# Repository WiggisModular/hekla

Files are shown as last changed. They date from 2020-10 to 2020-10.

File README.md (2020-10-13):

# hekla

FeatherWing Eurorack module, optimised for the Feather M4 express. I designed it to act as a slow LFO using DAC0 and DAC1 for two channels. 

## Resources (AKA giants on which shoulder I built)

### Featherwing

https://forum.kicad.info/t/designing-featherwings-in-kicad/6115/2

### Outputs and stuff: 

https://blog.thea.codes/designing-big-honking-button/

BTW: Follow her on twitter, read her blog, buy her modules. Wholesome content from a kickass person.

### Frontpanel copper layer 

Original data https://commons.wikimedia.org/wiki/File:Hekla1980.jpg#/media/File:Hekla1980.jpg

## Production files

Gerber, a schematic and a placement drawing, as well as a BOM and a pick and place file to get the SMD parts assembled over at JLCPCB will be available as releases as soon as I tested the first batch.

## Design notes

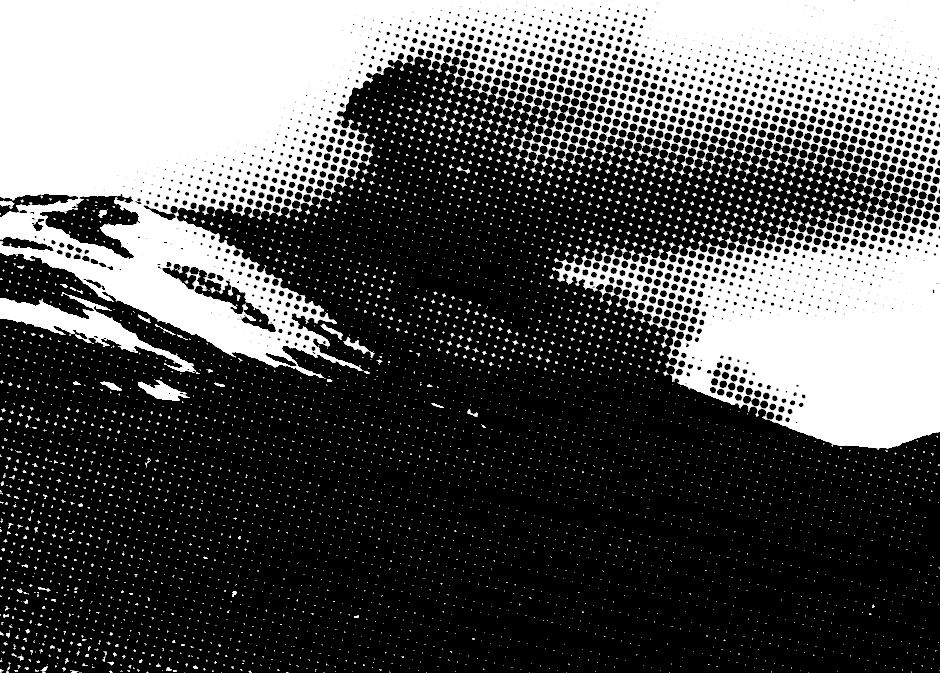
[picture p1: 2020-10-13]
panel/bg.jpg

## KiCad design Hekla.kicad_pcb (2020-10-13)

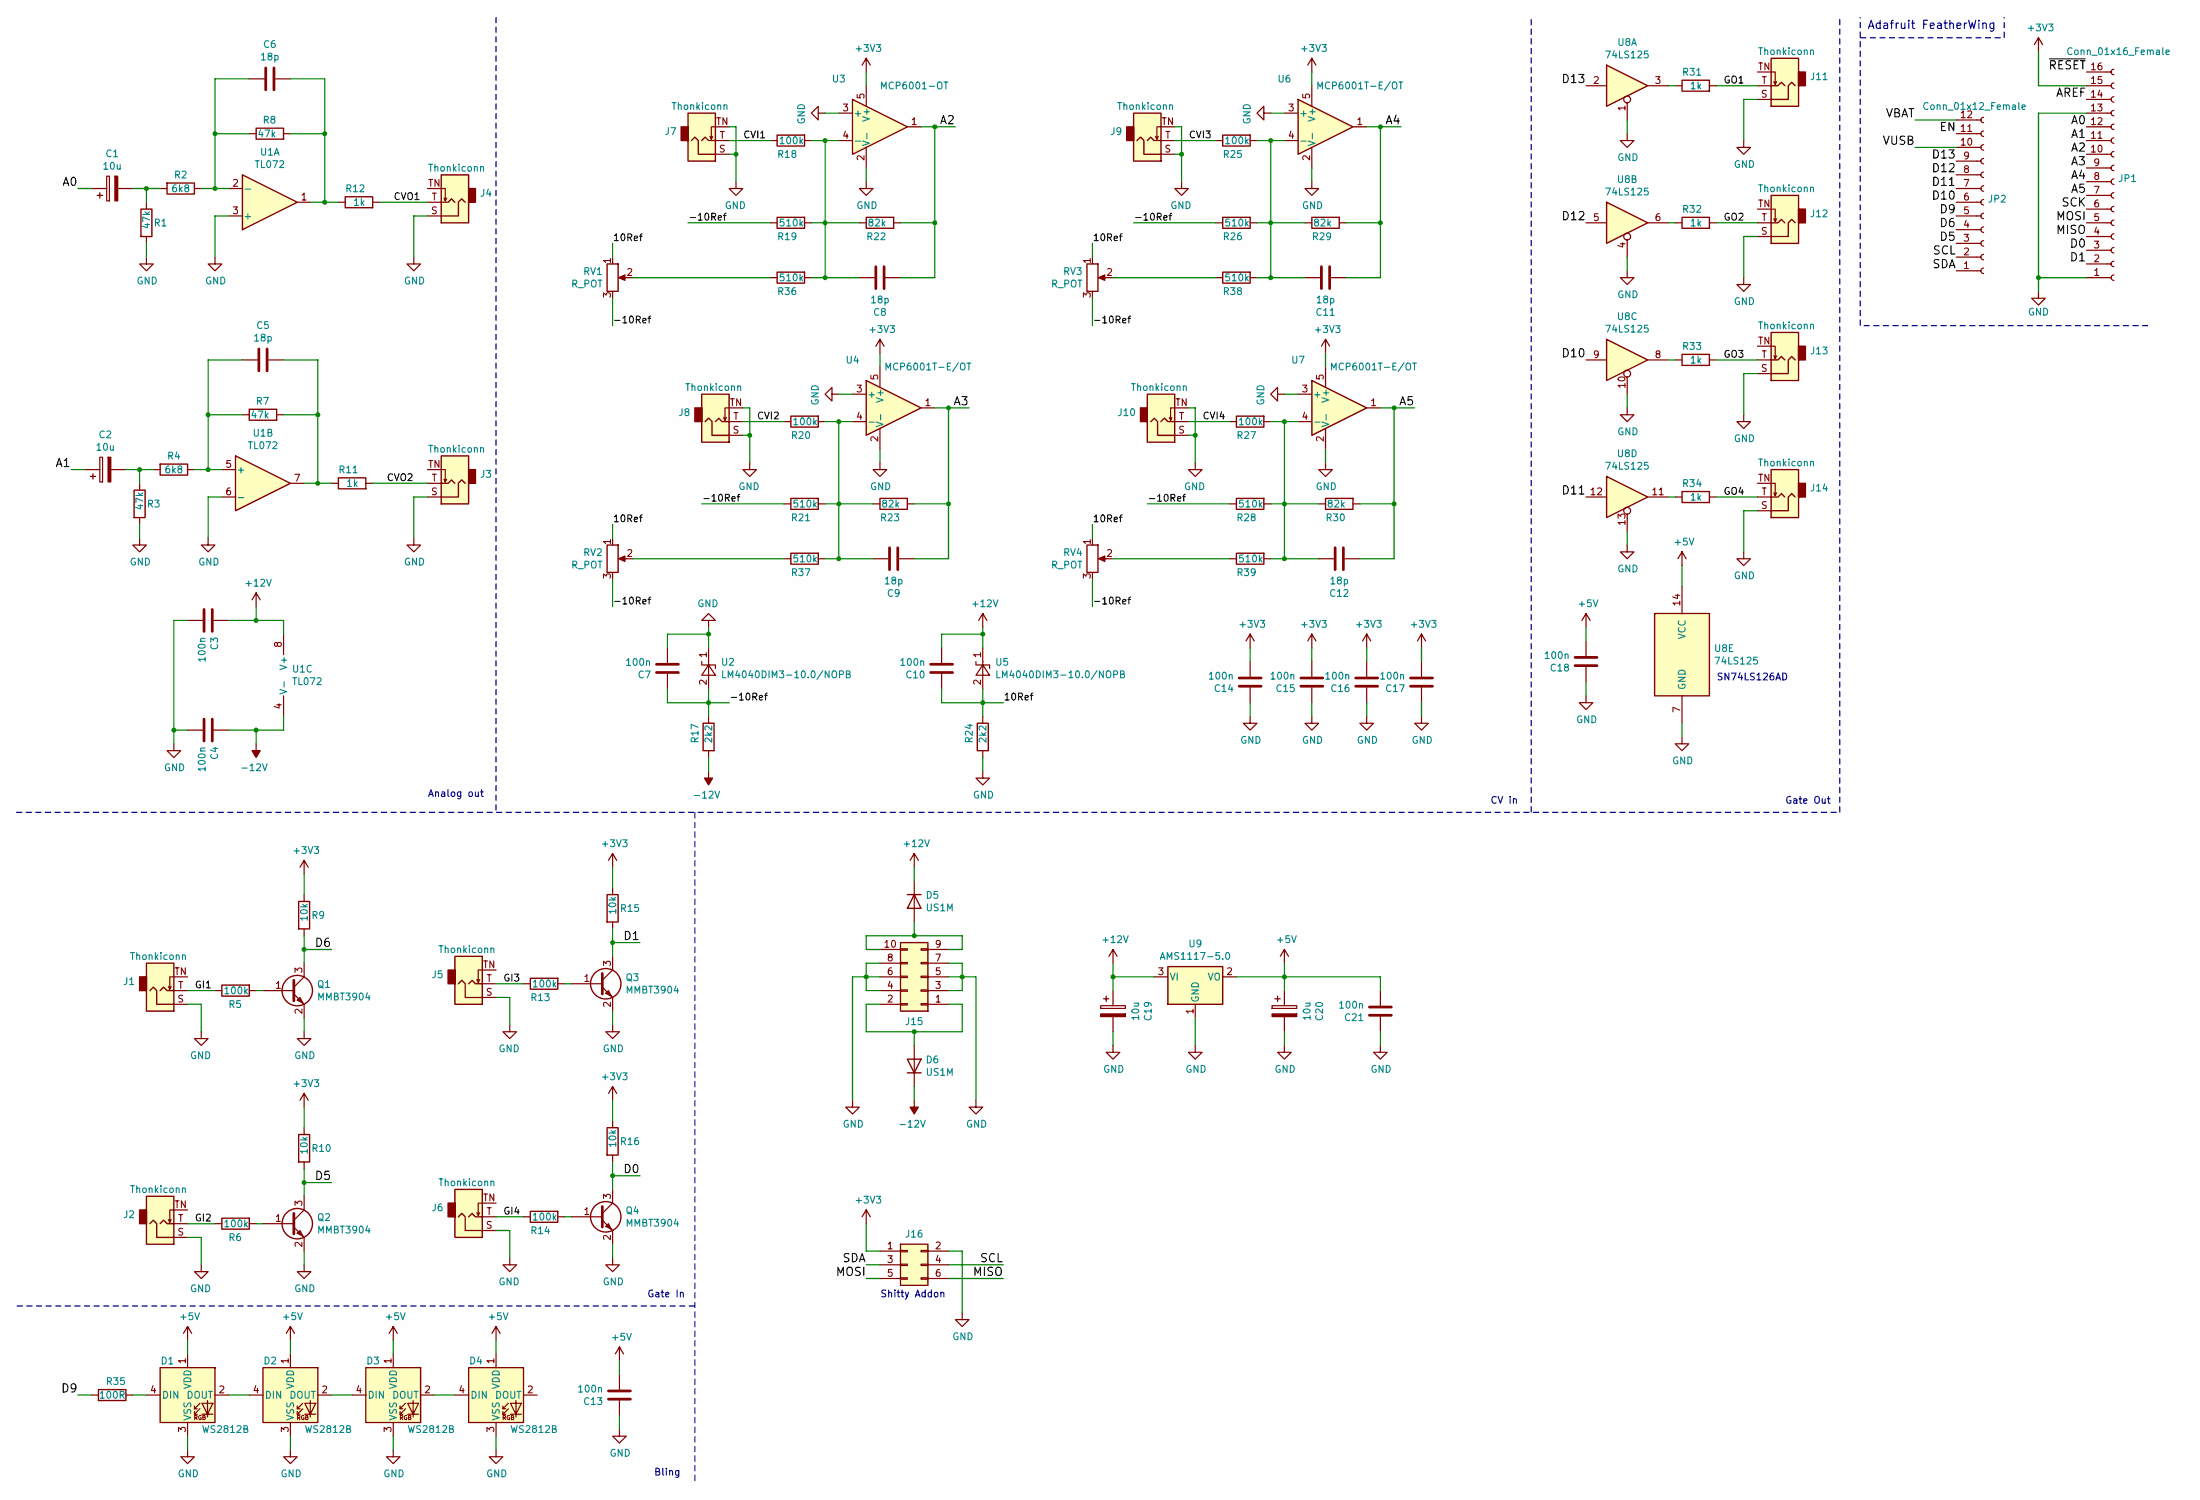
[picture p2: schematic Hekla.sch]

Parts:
C1, C2, C19, C20: 10u; CP_Elec_3x5.3; LCSC C249452
C3, C4, C7, C10, C13, C14, C15, C16, C17, C18, C21: 100n; C_0603_1608Metric_Pad1.05x0.95mm_HandSolder; LCSC C14663
C5, C6, C8, C9, C11, C12: 18p; C_0603_1608Metric_Pad1.05x0.95mm_HandSolder; LCSC C1647
D1, D2, D3, D4: WS2812B; LED_WS2812B_PLCC4_5.0x5.0mm_P3.2mm
D5, D6: US1M; D_SMA; LCSC C412437
J1, J2, J3, J4, J5, J6, J7, J8, J9, J10, J11, J12, J13, J14: Thonkiconn; Jack_3.5mm_QingPu_WQP-PJ398SM_Vertical_CircularHoles
J15: Conn_02x05_Odd_Even; PinSocket_2x05_P2.54mm_Vertical
J16: Conn_02x03_Odd_Even; PinSocket_2x03_P2.54mm_Vertical
JP1: Conn_01x16_Female; PinSocket_1x16_P2.54mm_Vertical
JP2: Conn_01x12_Female; PinSocket_1x12_P2.54mm_Vertical
Q1, Q2, Q3, Q4: MMBT3904; SOT-23; LCSC C20526
R1, R3, R7, R8: 47k; R_0603_1608Metric_Pad1.05x0.95mm_HandSolder; LCSC C25819
R2, R4: 6k8; R_0603_1608Metric_Pad1.05x0.95mm_HandSolder; LCSC C23212
R5, R6, R13, R14, R18, R20, R25, R27: 100k; R_0603_1608Metric_Pad1.05x0.95mm_HandSolder; LCSC C25803
R9, R10, R15, R16: 10k; R_0603_1608Metric_Pad1.05x0.95mm_HandSolder; LCSC C25804
R11, R12, R31, R32, R33, R34: 1k; R_0603_1608Metric_Pad1.05x0.95mm_HandSolder; LCSC C21190
R17, R24: 2k2; R_0603_1608Metric_Pad1.05x0.95mm_HandSolder; LCSC C4190
R19, R21, R26, R28, R36, R37, R38, R39: 510k; R_0603_1608Metric_Pad1.05x0.95mm_HandSolder; LCSC C23192
R22, R23, R29, R30: 82k; R_0603_1608Metric_Pad1.05x0.95mm_HandSolder; LCSC C23254
R35: 100R; R_0603_1608Metric_Pad1.05x0.95mm_HandSolder; LCSC C22775
RV1, RV2, RV3, RV4: R_POT; Potentiometer_Alps_RK09L_Single_Vertical
U1: TL072; SOIC-8_3.9x4.9mm_P1.27mm; LCSC C6961
U2, U5: LM4040DIM3-10.0/NOPB; SOT-23; LCSC C129969
U3: MCP6001-OT; SOT-23-5; LCSC C29429
U4, U6, U7: MCP6001T-E/OT; SOT-23-5; LCSC C29429
U8: 74LS125; SOIC-14_3.9x8.7mm_P1.27mm; LCSC C7734
U9: AMS1117-5.0; SOT-223-3_TabPin2; LCSC C6187

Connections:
+3V3: C14.1, C15.1, C16.1, C17.1, J16.1, JP1.15, R9.1, R10.1, R15.1, R16.1, U3.5 (V+), U4.5 (V+), U6.5 (V+), U7.5 (V+)
+5V: C13.1, C18.1, C20.1, C21.1, D1.1 (VDD), D2.1 (VDD), D3.1 (VDD), D4.1 (VDD), U8.14 (VCC), U9.2 (VO)
+12V: C3.2, C10.1, C19.1, D5.1 (K), U1.8 (V+), U5.1 (K), U9.3 (VI)
-12V: C4.2, D6.1 (K), R17.2, U1.4 (V-)
/10Ref: C10.2, R24.1, RV1.1, RV2.1, RV3.1, RV4.1, U5.2 (A)
/-10Ref: C7.2, R17.1, R19.1, R21.1, R26.1, R28.1, RV1.3, RV2.3, RV3.3, RV4.3, U2.2 (A)
/A0: C1.1, JP1.12
/A1: C2.1, JP1.11
/A2: C8.1, JP1.10, R22.2, U3.1
/A3: C9.1, JP1.9, R23.2, U4.1
/A4: C11.1, JP1.8, R29.2, U6.1
/A5: C12.1, JP1.7, R30.2, U7.1
/AREF: JP1.14
/CVI1: J7.T, R18.1
/CVI2: J8.T, R20.1
/CVI3: J9.T, R25.1
/CVI4: J10.T, R27.1
/CVO1: J4.T, R12.2
/CVO2: J3.T, R11.2
/D0: JP1.3, Q4.3 (C), R16.2
/D1: JP1.2, Q3.3 (C), R15.2
/D5: JP2.3, Q2.3 (C), R10.2
/D6: JP2.4, Q1.3 (C), R9.2
/D9: JP2.5, R35.2
/D10: JP2.6, U8.9
/D11: JP2.7, U8.12
/D12: JP2.8, U8.5
/D13: JP2.9, U8.2
/EN: JP2.11
/GI1: J1.T, R5.1
/GI2: J2.T, R6.1
/GI3: J5.T, R13.1
/GI4: J6.T, R14.1
/GO1: J11.T, R31.2
/GO2: J12.T, R32.2
/GO3: J13.T, R33.2
/GO4: J14.T, R34.2
/MISO: J16.6, JP1.4
/MOSI: J16.5, JP1.5
/SCK: JP1.6
/SCL: J16.4, JP2.2
/SDA: J16.3, JP2.1
/VBAT: JP2.12
/VUSB: JP2.10
/~RESET: JP1.16
GND: C3.1, C4.1, C7.1, C13.2, C14.2, C15.2, C16.2, C17.2, C18.2, C19.2, C20.2, C21.2, D1.3 (VSS), D2.3 (VSS), D3.3 (VSS), D4.3 (VSS), J1.S, J2.S, J3.S, J4.S, J5.S, J6.S, J7.S, J7.TN, J8.S, J8.TN, J9.S, J9.TN, J10.S, J10.TN, J11.S, J12.S, J13.S, J14.S, J15.3, J15.4, J15.5, J15.6, J15.7, J15.8, J16.2, JP1.1, JP1.13, Q1.2 (E), Q2.2 (E), Q3.2 (E), Q4.2 (E), R1.2, R3.2, R24.2, U1.3 (+), U1.6 (-), U2.1 (K), U3.2 (V-), U3.3 (+), U4.2 (V-), U4.3 (+), U6.2 (V-), U6.3 (+), U7.2 (V-), U7.3 (+), U8.1, U8.4, U8.7 (GND), U8.10, U8.13, U9.1 (GND)
unnamed: C1.2, R1.1, R2.2
unnamed: C2.2, R3.1, R4.2
unnamed: C5.1, R7.2, R11.1, U1.7
unnamed: C5.2, R4.1, R7.1, U1.5 (+)
unnamed: C6.1, R8.2, R12.1, U1.1
unnamed: C6.2, R2.1, R8.1, U1.2 (-)
unnamed: C8.2, R18.2, R19.2, R22.1, R36.2, U3.4 (-)
unnamed: C9.2, R20.2, R21.2, R23.1, R37.2, U4.4 (-)
unnamed: C11.2, R25.2, R26.2, R29.1, R38.2, U6.4 (-)
unnamed: C12.2, R27.2, R28.2, R30.1, R39.2, U7.4 (-)
unnamed: D1.2 (DOUT), D2.4 (DIN)
unnamed: D1.4 (DIN), R35.1
unnamed: D2.2 (DOUT), D3.4 (DIN)
unnamed: D3.2 (DOUT), D4.4 (DIN)
unnamed: D5.2 (A), J15.9, J15.10
unnamed: D6.2 (A), J15.1, J15.2
unnamed: Q1.1 (B), R5.2
unnamed: Q2.1 (B), R6.2
unnamed: Q3.1 (B), R13.2
unnamed: Q4.1 (B), R14.2
unnamed: R31.1, U8.3
unnamed: R32.1, U8.6
unnamed: R33.1, U8.8
unnamed: R34.1, U8.11
unnamed: R36.1, RV1.2
unnamed: R37.1, RV2.2
unnamed: R38.1, RV3.2
unnamed: R39.1, RV4.2

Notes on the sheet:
Adafruit FeatherWing
Analog out
CV in
Gate Out
Gate In
SN74LS126AD
Bling
Shitty Addon

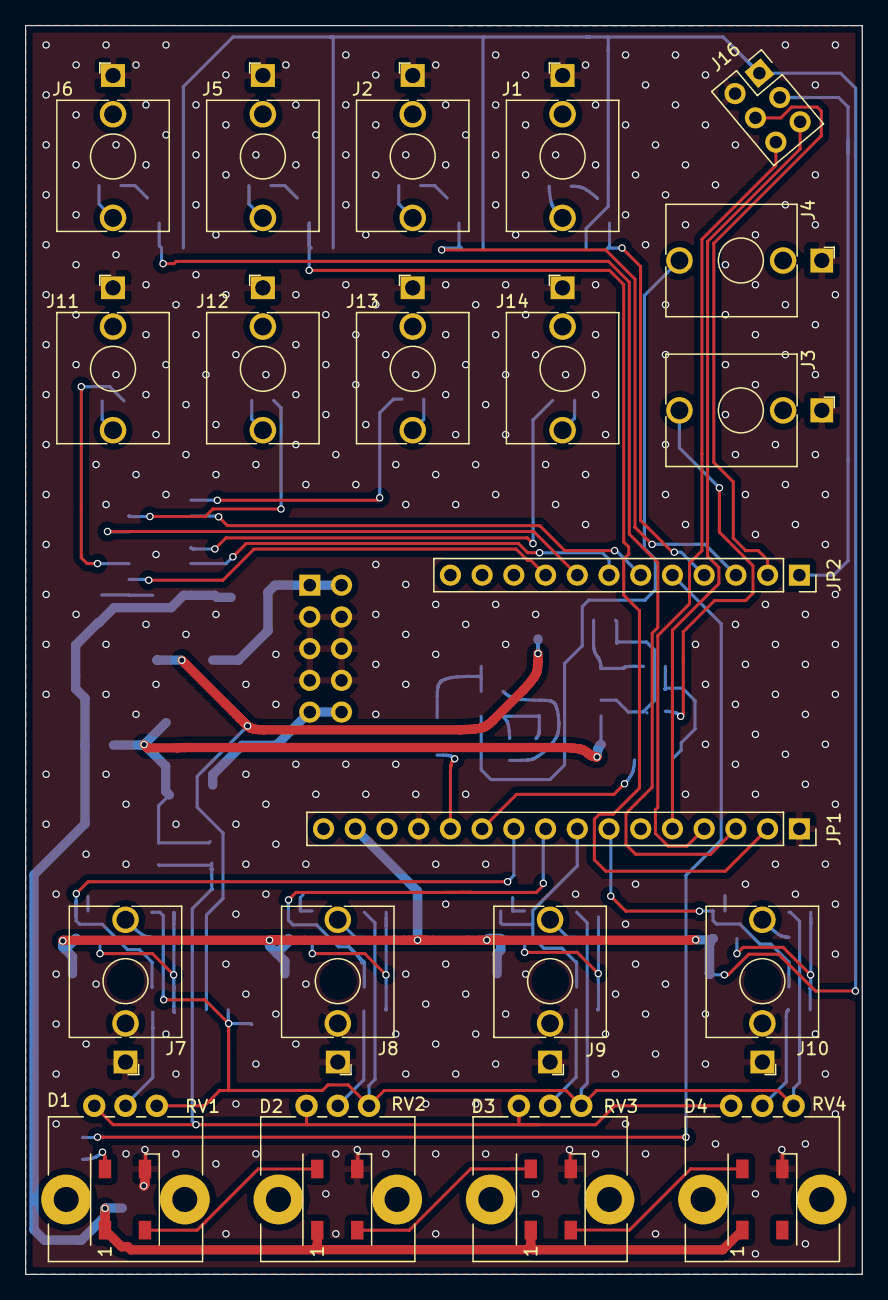
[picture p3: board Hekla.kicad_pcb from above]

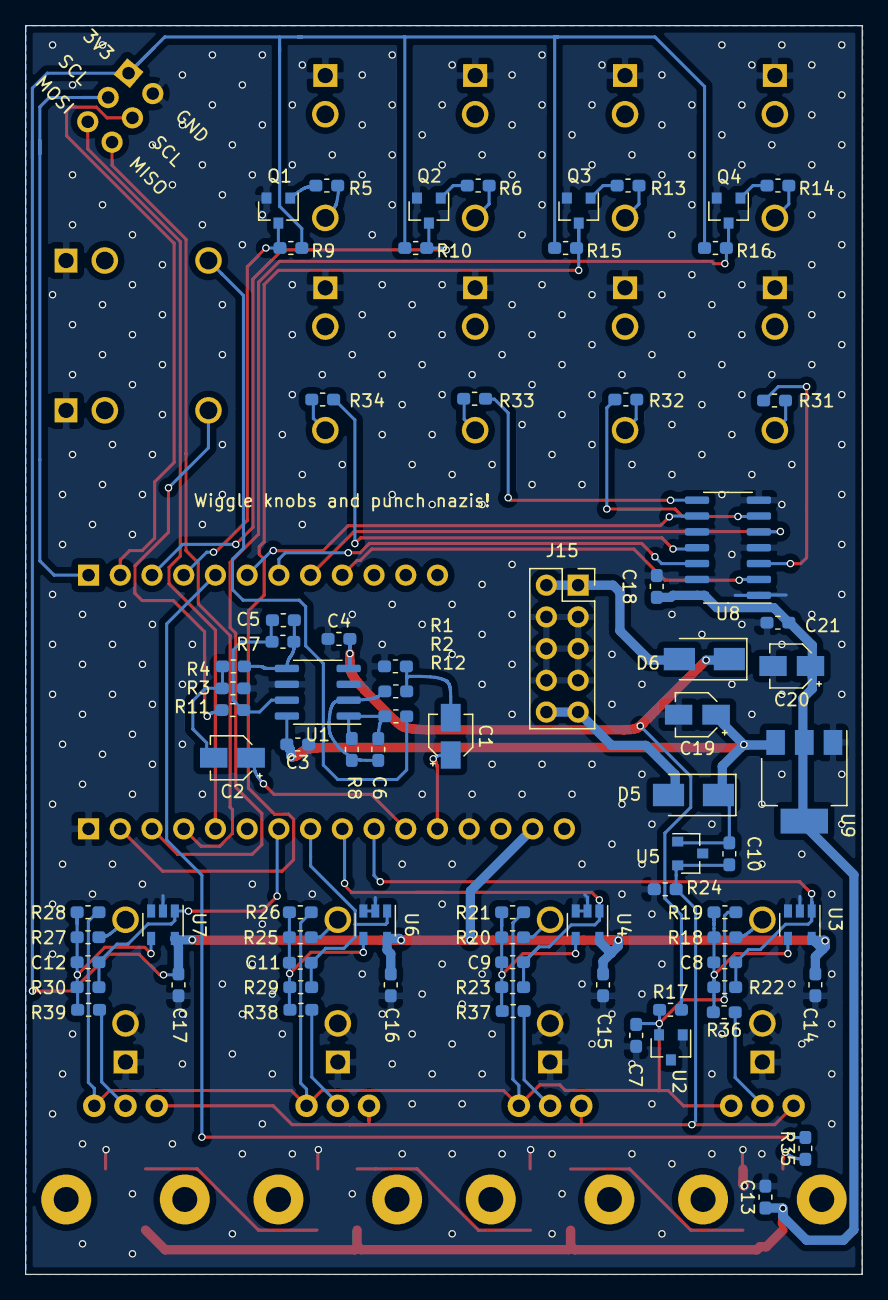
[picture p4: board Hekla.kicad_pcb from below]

Board: 2 copper layers, 67.0 x 100.0 mm, 101 parts (76 on the bottom side), 68 nets.

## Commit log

2020-10-13 Panel artwork done
    [panel.kicad_pcb]
2020-10-13 First revision sent to production
    [Hekla.kicad_pcb, Hekla.sch]
